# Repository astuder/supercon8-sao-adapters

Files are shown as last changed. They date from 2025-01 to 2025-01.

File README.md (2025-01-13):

We love the [Hackaday Supercon 8 Add On Badge](https://github.com/Hack-a-Day/2024-Supercon-8-Add-On-Badge),
but in our opinion it has two major design flaws:
1. 4 out of 6 SAO slots are oriented sideways or upside-down
2. there is a large empty area in the center of the badge

We present two simple adapters to solve these issues.

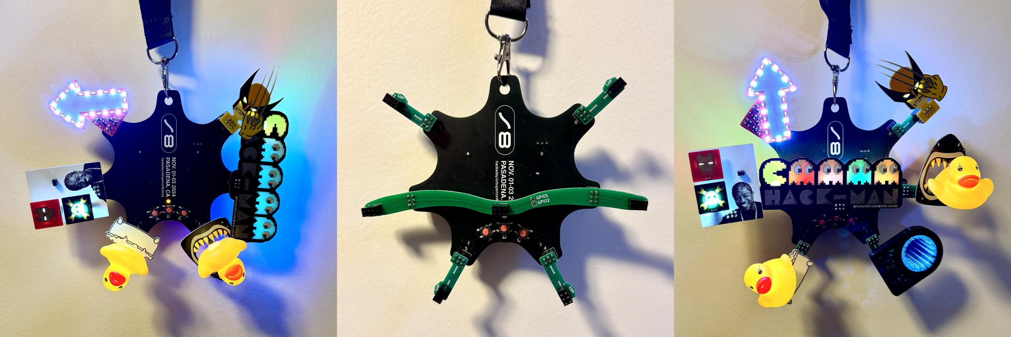
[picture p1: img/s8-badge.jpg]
Supercon 8 badge without and with adapters

(see note below for links to the SAOs shown)

**SAO Up** rotates the SAO slot by 90 degrees, orienting SAOs closer to
their upright position. The same PCB works for the left and right side
of the badge, depending on which side the SAO headers are soldered.

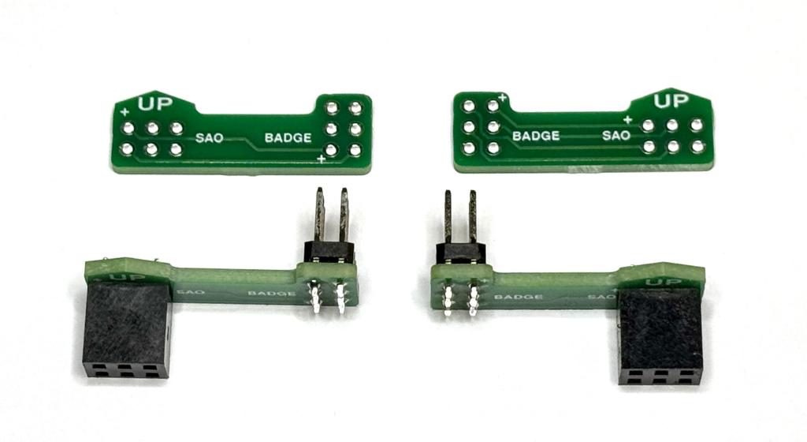
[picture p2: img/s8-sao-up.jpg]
SAO Up adapter


**SAO Bridge** adds an SAO slot in the center of the badge, and also
rotates the left and right SAO slots into upright orientation. The center
slot is connected to power and I2C of the bus on the left side of the
badge (slot 2).

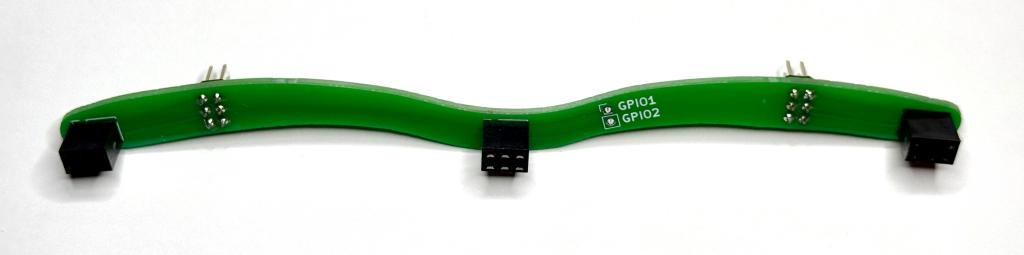
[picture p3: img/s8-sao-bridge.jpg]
SAO Bridge adapter


Black would have been the logical color for the adapters. But we only had
10 days between [badge reveal](https://hackaday.com/2024/10/22/the-2024-hackaday-supercon-sao-badge-reveal/)
and the event, so we went with green as that offered the fastest
turnaround time at JLCPCB.

You are welcome to duplicate, adapt or steal this project. The license is
CERN-OHL-P, which is open and permissive.

**SAOs used for demo**

Here's a list of the SAOs shown in the photos above:
* [duckGLOW](https://hackaday.io/project/198918-duckglow-sao) by myself
* [Hack-Man](https://hackaday.io/project/198301-hack-man-sao) by InstantArcade
* [Featuring You!](https://hackaday.io/project/198924-featuring-you) by Nanik Adnani
* [Yo Dawg](https://hackaday.io/project/198060-yo-dawg-sao-introducing-saoao) by davedarko
* [Infinity Mirror](https://hackaday.io/project/198943-sao-infinity-mirror) by Scorch Works
* [Wolverine](https://mastodon.social/@simenzhor/113266947534371773) by Simen E. Sørensen

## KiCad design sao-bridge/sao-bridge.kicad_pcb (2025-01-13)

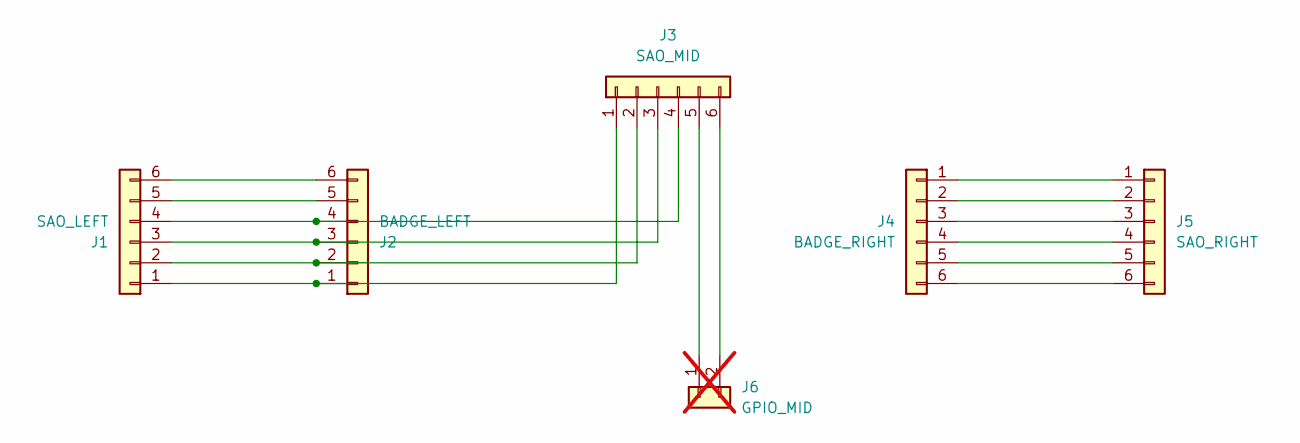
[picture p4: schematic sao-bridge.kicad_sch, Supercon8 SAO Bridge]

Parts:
J1: SAO_LEFT; PinSocket_2x03_P2.54mm_Vertical
J2: BADGE_LEFT; PinHeader_2x03_P2.54mm_Vertical
J3: SAO_MID; PinSocket_2x03_P2.54mm_Vertical
J4: BADGE_RIGHT; PinHeader_2x03_P2.54mm_Vertical
J5: SAO_RIGHT; PinSocket_2x03_P2.54mm_Vertical
J6: GPIO_MID; PinHeader_1x02_P2.54mm_Vertical; not fitted

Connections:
unnamed: J1.1, J2.1, J3.1
unnamed: J1.2, J2.2, J3.2
unnamed: J1.3, J2.3, J3.3
unnamed: J1.4, J2.4, J3.4
unnamed: J1.5, J2.5
unnamed: J1.6, J2.6
unnamed: J3.5, J6.1
unnamed: J3.6, J6.2
unnamed: J4.1, J5.1
unnamed: J4.2, J5.2
unnamed: J4.3, J5.3
unnamed: J4.4, J5.4
unnamed: J4.5, J5.5
unnamed: J4.6, J5.6

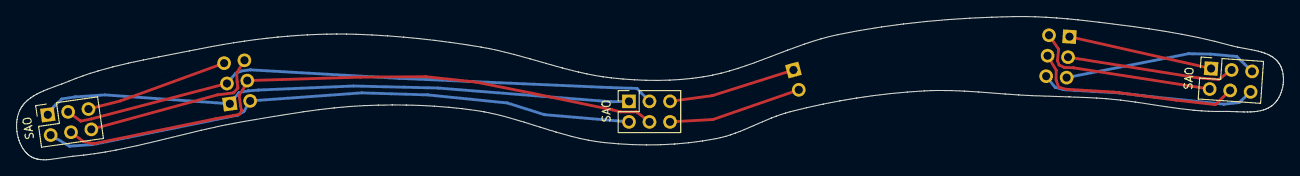
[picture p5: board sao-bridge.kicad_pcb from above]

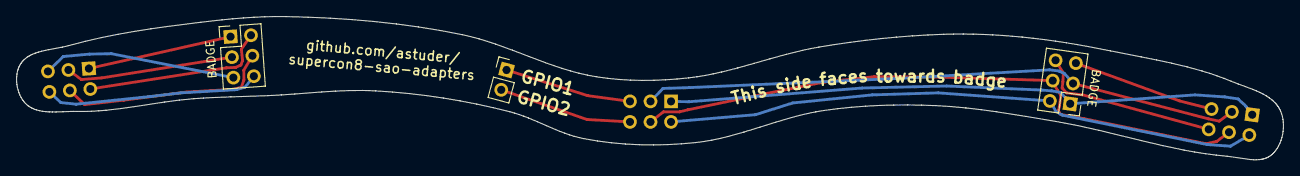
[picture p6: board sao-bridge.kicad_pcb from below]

Board: 2 copper layers, 156.8 x 17.7 mm, 6 parts (3 on the bottom side), 14 nets.

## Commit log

2025-01-13 add some info to bottom siklscreen
    [sao-bridge.kicad_pcb, sao-bridge.kicad_sch]
2025-01-13 bump version
    [sao-bridge.kicad_pcb, sao-bridge.kicad_sch]
